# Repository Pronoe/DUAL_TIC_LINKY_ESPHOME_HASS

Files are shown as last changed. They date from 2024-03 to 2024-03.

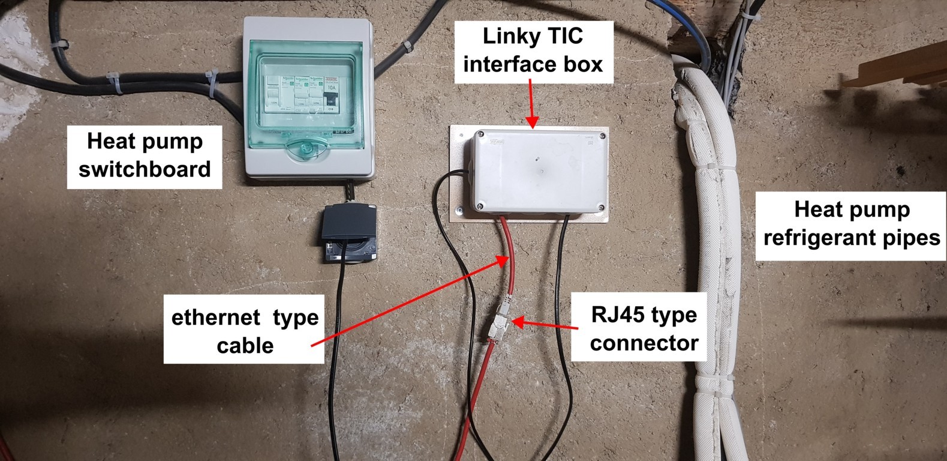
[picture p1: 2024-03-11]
Pictures/installed_linky_box.jpg

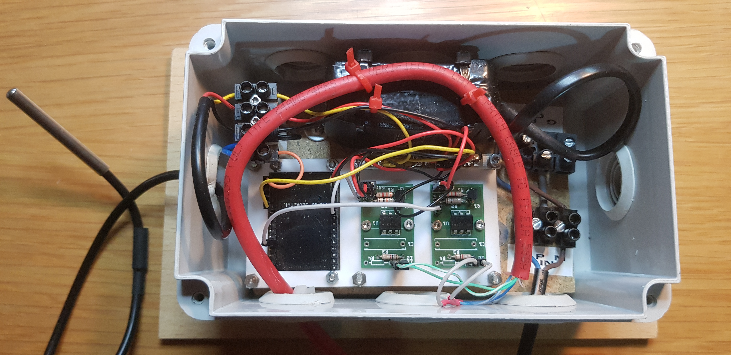
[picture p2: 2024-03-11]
Electronic definition/Pictures/20240217_154911.jpg

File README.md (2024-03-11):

Author: Patrick Souty
  
Dual `Linky` power meter monitoring with `Home Assistant` and `ESP32` for `TIC` data link interface
  
Based on following hardware:
  
- `ESP32` `DOIT-DEVT-KIT-V1` including module `ESP-WROOM32`
- `TIC` optocoupler interface boards
- 5.2V power supply
- 2 Power meters
  - French `Linky` type power meter with `TIC` data link (serial date @ 1200 or 9600 b/s over a 50 kHz carrier)

Software: 

- ` ESPHOME ` for the `ESP32` firmware with teleinfo driver
- `Home-assistant` app running on Raspberry PI3, for monitoring and data analysis

## Project description - English version ##

This project is dedicated to the monitoring of 2 distinct `Linky` power meter (French smart power meter) with a single `ESP32` module as the low level interface and `Home Assistant` for data monitoring.

`ESPHOME` is used to generate the ERSP32 firmware with the use of TELEINFO driver for the `TIC` data link interpretation.
It has been preferred to a `TASMOTA` solution because this later cannot be configured to monitor two separate data links.
Two interface boards based on an optocoupler H11AA1 are used for the `TIC` signal demodulation and galvanic isolation.
This interface insures compliance to the Enedis-NOI-CPT_54E specification document.
There exists a lot of similar projects for the use of `TIC` power meter interface for energy monitoring but I have found none with the ability to monitor two power meter with a single `ESP32` module.

The overall electronic is housed inside a plastic box placed in the boiler room.
It is connected to the two power meters outside the house, through two twisted pairs from an Ethernet cable.
The `ESP32` communicates over Wi-Fi with `Home Assistant` running on a RPI 3B.

## Description du projet -  version Française  ##

Ce projet est destiné au suivi en temps réel des consommations électriques grâce à l'exploitation des liaisons de données `TIC` des compteurs `Linky`. Il utilise un module `ESP32` unique pour la dé-commutation des trames `TIC` des 2 compteurs `Linky` qui équipent ma maison.
Le 1er compteur est dédié presque uniquement à la pompe à chaleur qui chauffe la maison et le 2ème couvre tous les autres usages.
Cela a permis de conserver des contrats de 9 kVA et surtout une installation en monophasé.

`ESPHOME` a été utilisé pour le firmware de l'ERSP32 en le compilant avec le driver TELEINFO  pour la dé-commutation de la liaison `TIC`.
J'ai testé également la solution `TASMOTA` qui était légèrement plus simple à mettre en oeuvre mais je ne l'ai pas retenu car elle ne permet malheureusement pas de gérer simultanément 2 liaisons `TIC`.
Deux cartes d'interface basées sur un optocoupler H11AA1 sont utilisées pour la démodulation du signal `TIC` et pour l'isolation galvanique.
Ces cartes sont nécessaires pour assurer la conformité au document de spécification Enedis-NOI-CPT_54E et pour assurer l'interface avec l'ERC32.
Il existe de nombreux projets similaires destinés à s'interfacer avec les compteurs `Linky` mais je n'en ai trouvé aucun permettant de se connecteur à 2 compteurs simultanément avec un seul module `ESP32`, d'où ce projet spécifique.

L'ensemble de l'électronique est logée dans un boîtier de raccordement électrique et installée dans le local chaufferie.
Elle est connectée aux 2 compteurs à l'extérieur de la maison grâce à un câble Ethernet de 10 m dont 2 des 4 paires torsadées sont utilisées.
Le module `ESP32` communique en Wi-Fi avec `Home Assistant` qui tourne sur un RPI 3B.

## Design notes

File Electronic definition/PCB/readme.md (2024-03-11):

PCB was designed with Fritzing software and manufactured by Aisler Gmbh

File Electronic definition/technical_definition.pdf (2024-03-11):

# LINKY Power Meter interface with ESP32, Zigbee and Home Assistant

## OVERALL ARCHITECTURE

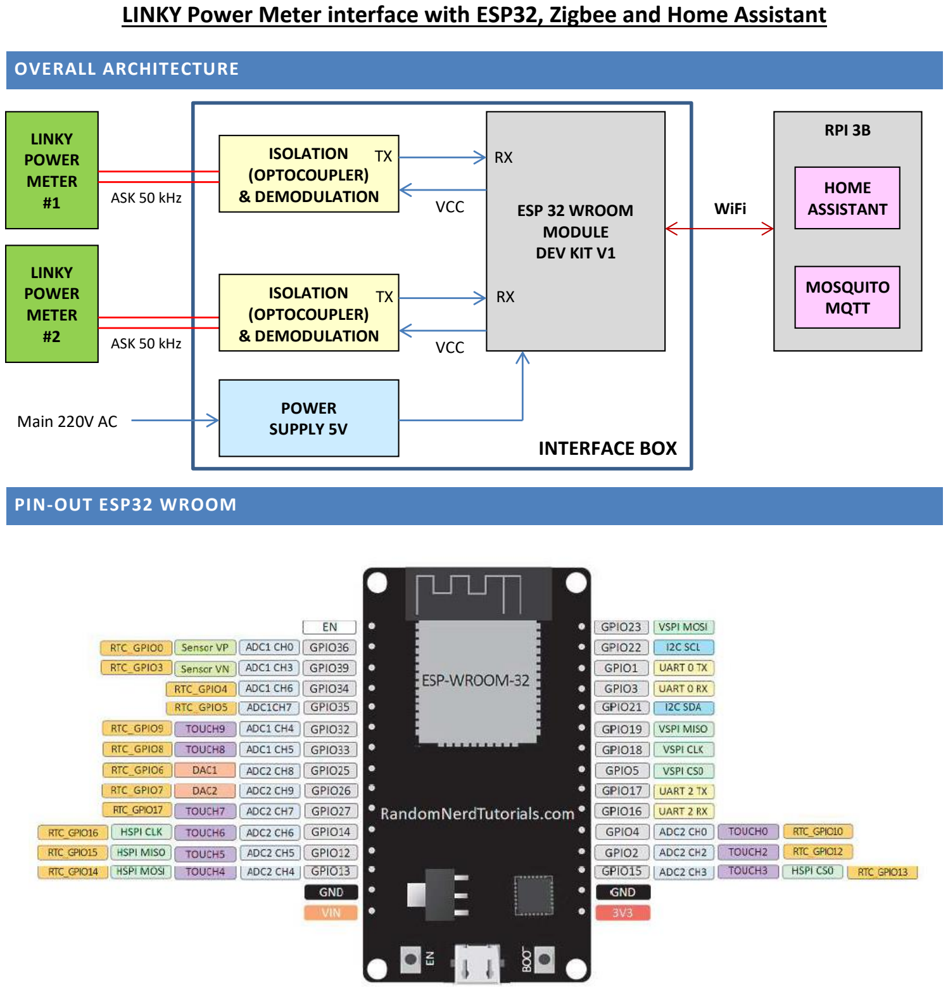
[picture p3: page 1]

## PIN-OUT ESP32 WROOM

## INTERFACE BOX

### LINKY POWER METER

#1

### LINKY POWER METER

#2

### ISOLATION (OPTOCOUPLER)

ASK 50 kHz | & DEMODULATION

ASK 50 kHz

### ISOLATION (OPTOCOUPLER) & DEMODULATION

### ESP 32 WROOM MODULE DEV KIT V1

TX

TX

### VCC

### VCC

RX

RX

### POWER SUPPLY 5V Main 220V AC

### RPI 3B

### HOME ASSISTANT

### MOSQUITO MQTT

### WiFi

## PINOUT OF ERC32 (NOT THE MODULE PINOUT)

Name | No. | Type | Function
GND | 1 | P | Ground
3V3 | 2 | P | Power supply
EN | 3 | I | Module-enable signal. Active high.
SENSOR_VP | 4 | I | GPIO36, ADC1_CH0, RTC_GPIO0
SENSOR_VN | 5 | I | GPIO39, ADC1_CH3, RTC_GPIO3
IO34 | 6 | I | GPIO34, ADC1_CH6, RTC_GPIO4
IO35 | 7 | I | GPIO35, ADC1_CH7, RTC_GPIO5
IO32 | 8 | I/O | GPIO32, XTAL_32K_P (32.768 kHz crystal oscillator input), ADC1_CH4, TOUCH9, RTC_GPIO9
IO33 | 9 | I/O | GPIO33, XTAL_32K_N (32.768 kHz crystal oscillator output), ADC1_CH5, TOUCH8, RTC_GPIO8
IO25 | 10 | I/O | GPIO25, DAC_1, ADC2_CH8, RTC_GPIO6, EMAC_RXD0
IO26 | 11 | I/O | GPIO26, DAC_2, ADC2_CH9, RTC_GPIO7, EMAC_RXD1
IO27 | 12 | I/O | GPIO27, ADC2_CH7, TOUCH7, RTC_GPIO17, EMAC_RX_DV
IO14 | 13 | I/O | GPIO14, ADC2_CH6, TOUCH6, RTC_GPIO16, MTMS, HSPICLK, HS2_CLK, SD_CLK, EMAC_TXD2
IO12 | 14 | I/O | GPIO12, ADC2_CH5, TOUCH5, RTC_GPIO15, MTDI, HSPIQ, HS2_DATA2, SD_DATA2, EMAC_TXD3
GND | 15 | P | Ground
IO13 | 16 | I/O | GPIO13, ADC2_CH4, TOUCH4, RTC_GPIO14, MTCK, HSPID, HS2_DATA3, SD_DATA3, EMAC_RX_ER
SHD/SD2* | 17 | I/O | GPIO9, SD_DATA2, SPIHD, HS1_DATA2, U1RXD
SWP/SD3* | 18 | I/O | GPIO10, SD_DATA3, SPIWP, HS1_DATA3, U1TXD
SCS/CMD* | 19 | I/O | GPIO11, SD_CMD, SPICS0, HS1_CMD, U1RTS
SCK/CLK* | 20 | I/O | GPIO6, SD_CLK, SPICLK, HS1_CLK, U1CTS
SDO/SD0* | 21 | I/O | GPIO7, SD_DATA0, SPIQ, HS1_DATA0, U2RTS
SDI/SD1* | 22 | I/O | GPIO8, SD_DATA1, SPID, HS1_DATA1, U2CTS
IO15 | 23 | I/O | GPIO15, ADC2_CH3, TOUCH3, MTDO, HSPICS0, RTC_GPIO13, HS2_CMD, SD_CMD, EMAC_RXD3
IO2 | 24 | I/O | GPIO2, ADC2_CH2, TOUCH2, RTC_GPIO12, HSPIWP, HS2_DATA0, SD_DATA0
IO0 | 25 | I/O | GPIO0, ADC2_CH1, TOUCH1, RTC_GPIO11, CLK_OUT1, EMAC_TX_CLK
IO4 | 26 | I/O | GPIO4, ADC2_CH0, TOUCH0, RTC_GPIO10, HSPIHD, HS2_DATA1, SD_DATA1, EMAC_TX_ER
IO16 | 27 | I/O | GPIO16, HS1_DATA4, U2RXD, EMAC_CLK_OUT
IO17 | 28 | I/O | GPIO17, HS1_DATA5, U2TXD, EMAC_CLK_OUT_180
IO5 | 29 | I/O | GPIO5, VSPICS0, HS1_DATA6, EMAC_RX_CLK
IO18 | 30 | I/O | GPIO18, VSPICLK, HS1_DATA7
IO19 | 31 | I/O | GPIO19, VSPIQ, U0CTS, EMAC_TXD0
NC | 32 | - | -
IO21 | 33 | I/O | GPIO21, VSPIHD, EMAC_TX_EN
RXD0 | 34 | I/O | GPIO3, U0RXD, CLK_OUT2
TXD0 | 35 | I/O | GPIO1, U0TXD, CLK_OUT3, EMAC_RXD2
IO22 | 36 | I/O | GPIO22, VSPIWP, U0RTS, EMAC_TXD1
IO23 | 37 | I/O | GPIO23, VSPID, HS1_STROBE
GND | 38 | P | Ground

## I/O PINS SELECTION

HW function | PIN | Rational
Power Meter #1 data | GPIO35 (RX0) | Fully available – input only
Power Meter #2 data | GPIO16 (RX2) | Fully available
Temp sensor DS18B20 communication | GPIO14 | Fully available

Note: pullup resistor 4,7 kohm required on temp. sensor data line.

## SCHEMATIC

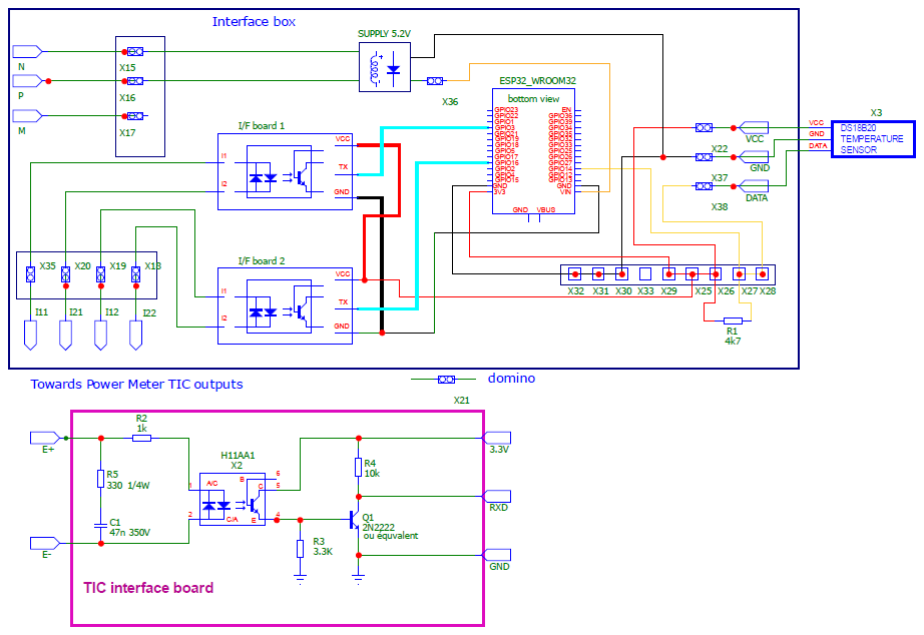
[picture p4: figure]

## PCB ATTACHMENT

### - PCB bracket FDM printing in PLA, with elevation feet - ESP board attached beneath the bracket with electronic parts on the bottom - Interface boards attached over the bracket with electronic parts on the top

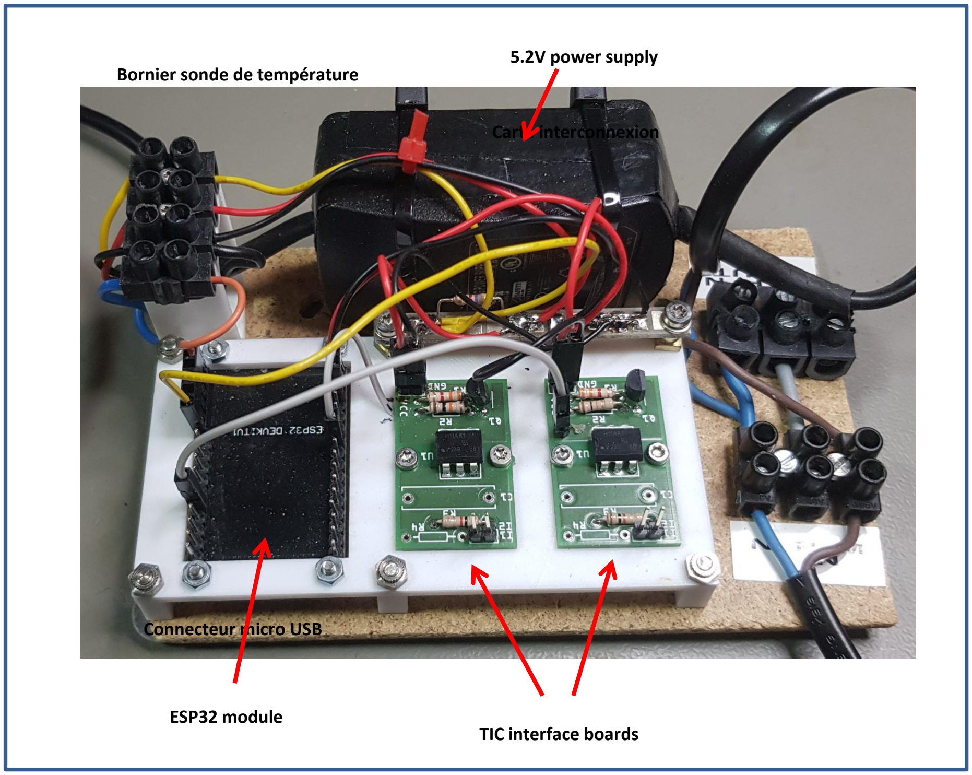
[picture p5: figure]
Connecteur micro USB; 5.2V power supply; Carte interconnexion; Bornier sonde de température; TIC interface boards; ESP32 module

## FINAL HARDWARE IMPLEMENTATION

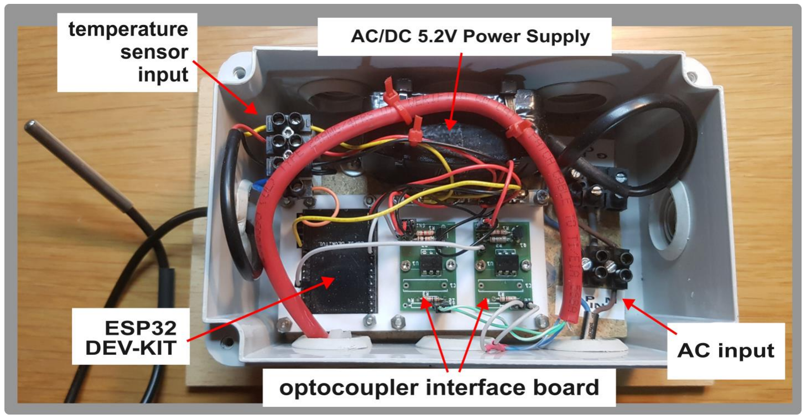
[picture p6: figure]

## POWER CONSUMPTION

### Measurement with a power meter → below 1W

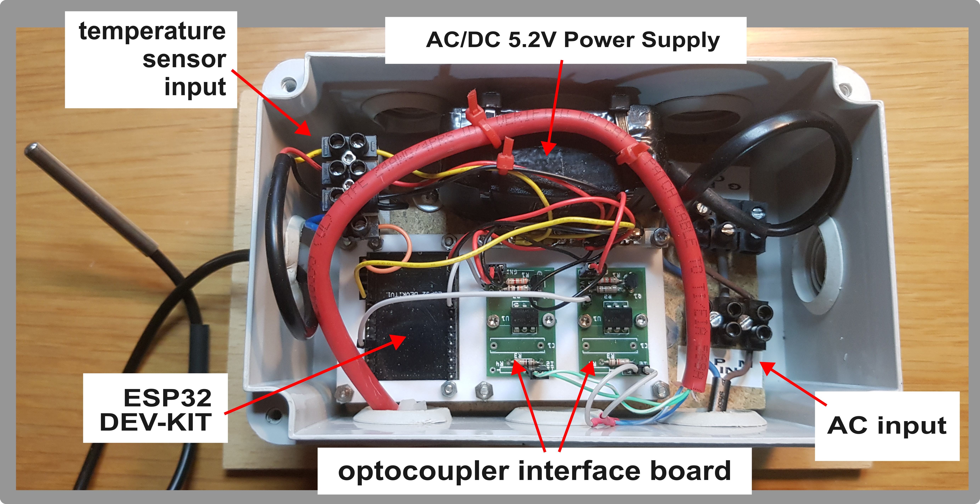
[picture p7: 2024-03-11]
Electronic definition/Pictures/20240217_154911_label.jpg

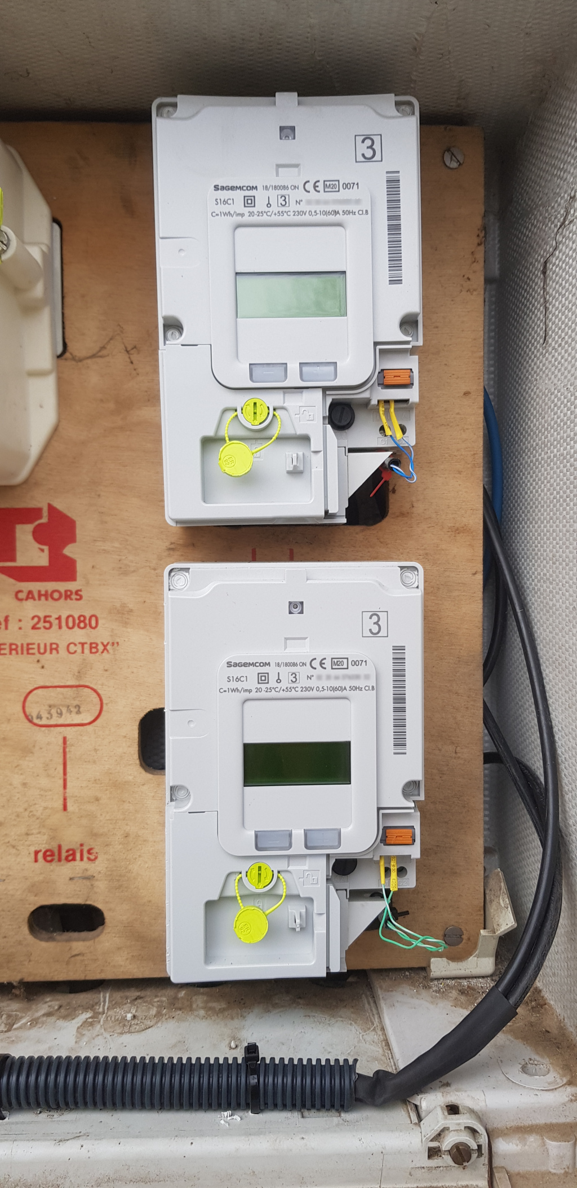
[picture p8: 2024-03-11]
Pictures/meter_cables .jpg

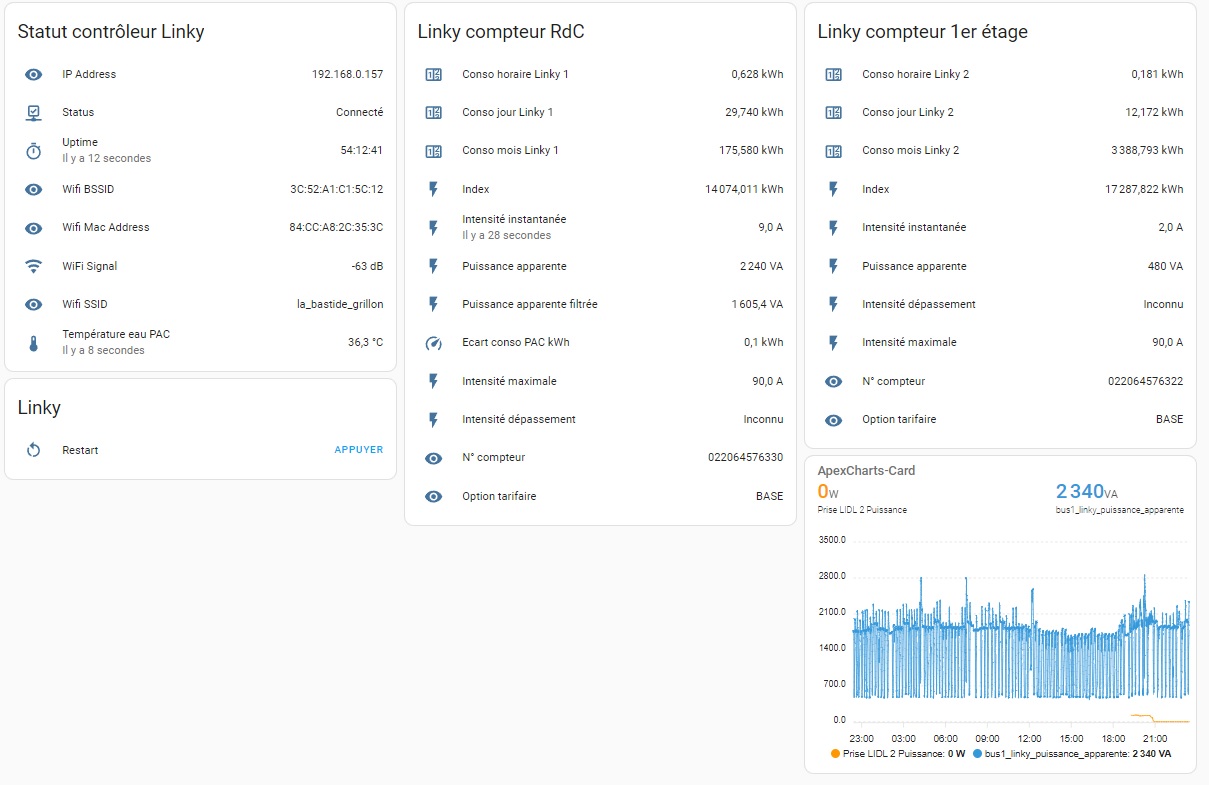
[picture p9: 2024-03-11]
Pictures/home_assistant_dashboard_.jpg

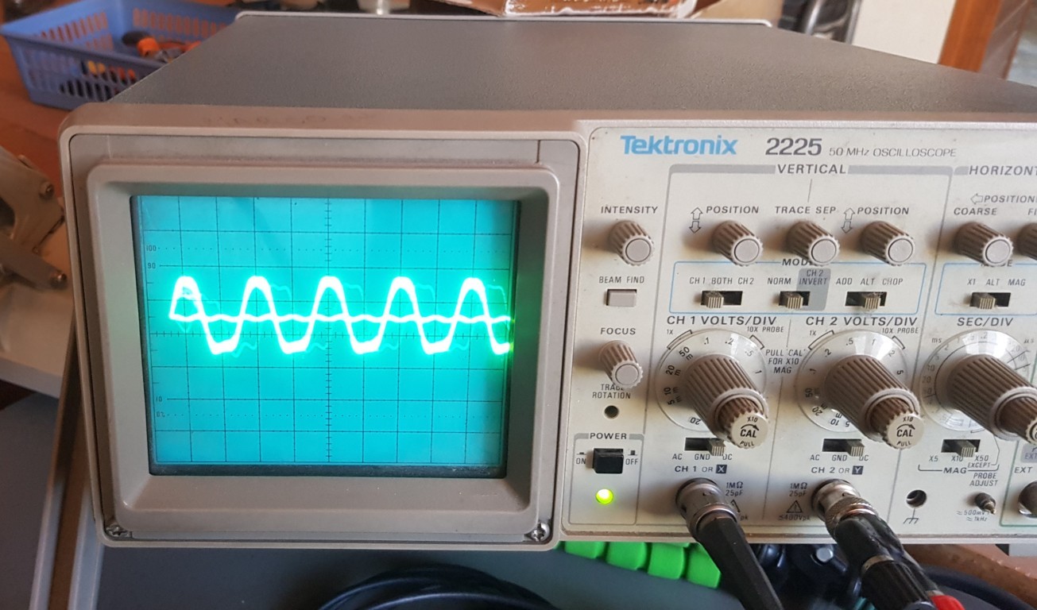
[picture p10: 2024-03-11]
Pictures/TIC_signal.jpg

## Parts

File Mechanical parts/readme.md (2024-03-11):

Mechanical parts (PCB stand and washers) designed with FreeCAD software and 3D printed.

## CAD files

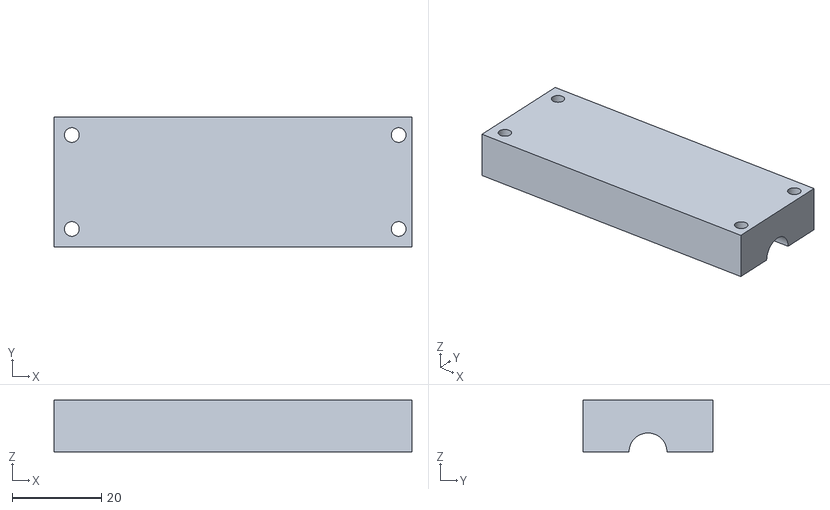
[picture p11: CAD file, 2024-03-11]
Mechanical parts/boitier_RJ45-Demi_boite2.stl
80.4 x 29.1 x 11.6

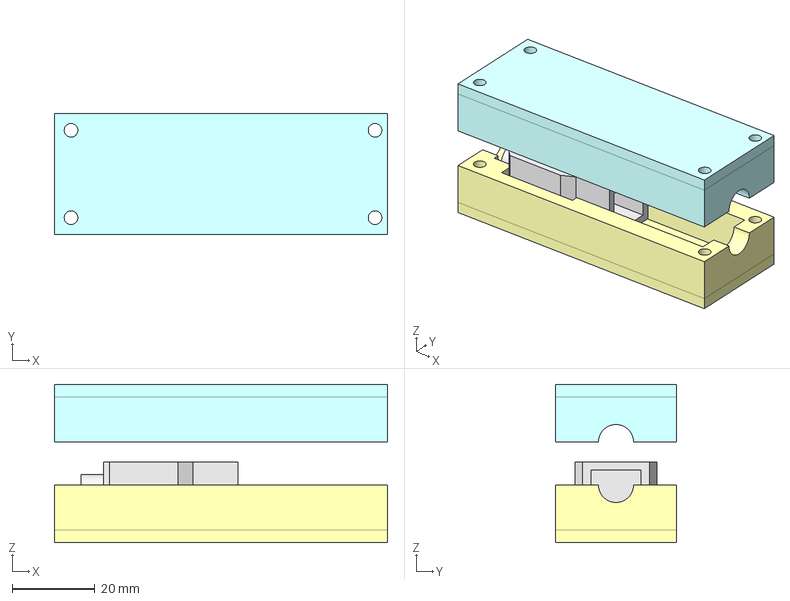
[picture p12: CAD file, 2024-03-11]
Mechanical parts/boitier_RJ45.FCStd
80.4 x 29.1 x 38.2 mm
Modèle connecteur femelle
Demi_boite1
Demi_boite1 (Mirror #1)

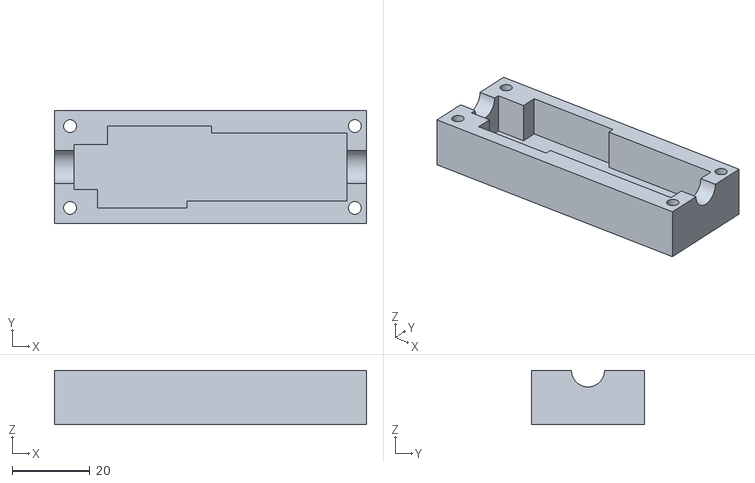
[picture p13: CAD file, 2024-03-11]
Mechanical parts/boitier_RJ45_large.stl
80.4 x 29.1 x 13.9

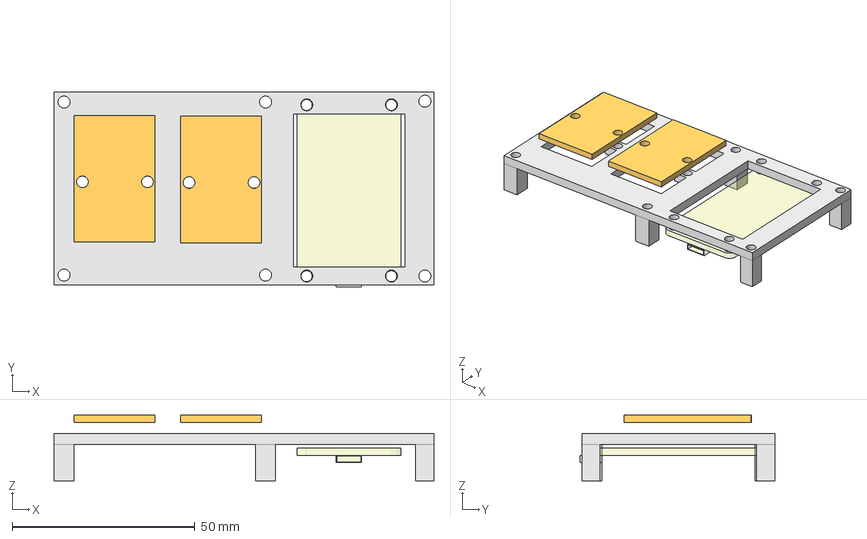
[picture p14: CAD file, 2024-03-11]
Mechanical parts/stand.FCStd
104.1 x 53.4 x 18.0 mm
stand
PCB_KIT_WROOM32
PCB opto
PCB opto001

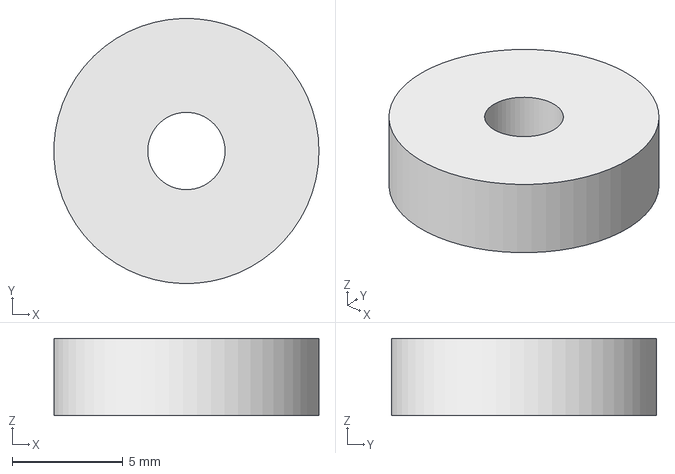
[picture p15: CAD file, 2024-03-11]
Mechanical parts/washer_12x3.5x3.5.FCStd
12.0 x 12.0 x 3.50 mm

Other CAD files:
Mechanical parts/boitier_RJ45.stl
Mechanical parts/stand.stl
Mechanical parts/washer_12x3.5x3.5.stl

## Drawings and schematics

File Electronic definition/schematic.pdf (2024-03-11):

## SUPPLY 5.2V

I/F board 1 | DS18B20

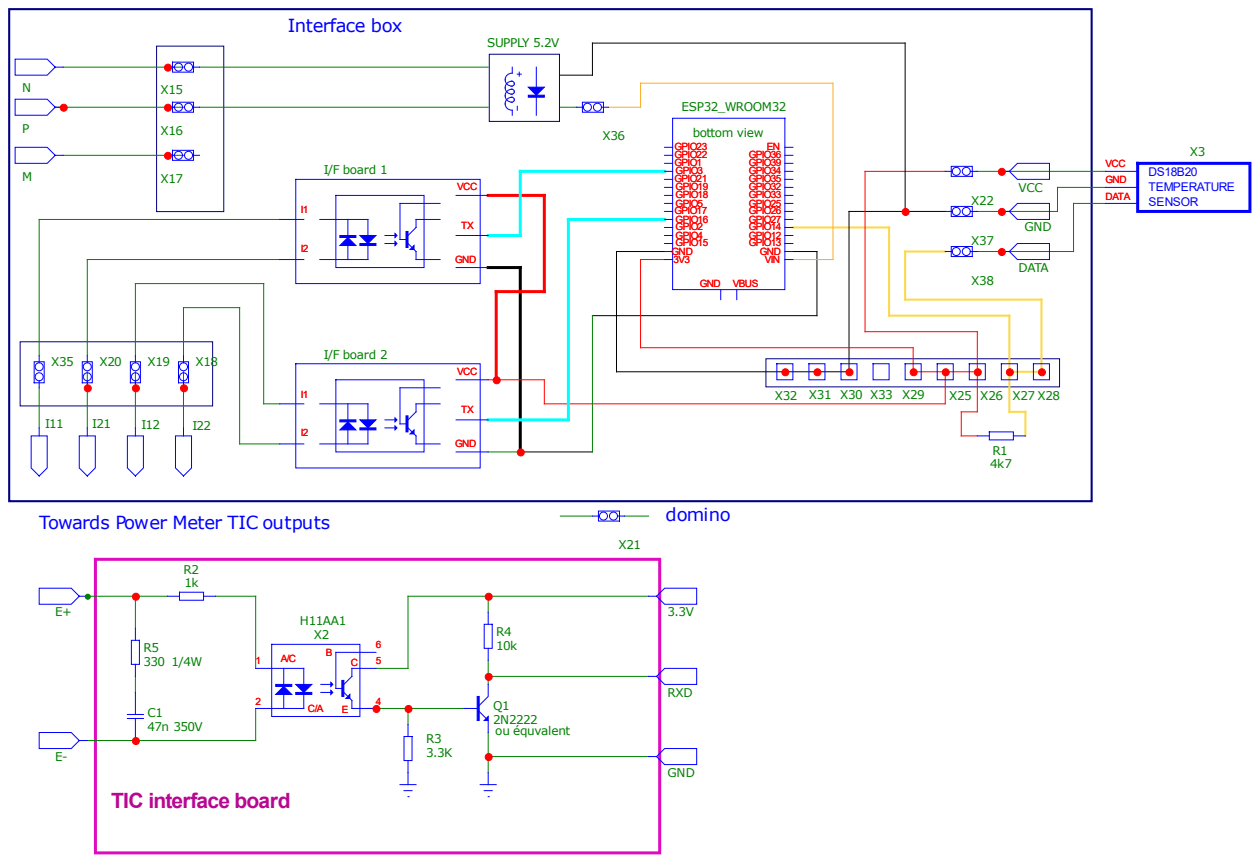
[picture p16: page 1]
GND; VCC; VCC GND DATA; GPIO23 GPIO22 GPIO1 GPIO3 GPIO21 GPIO19 GPIO18 GPIO5 GPIO17 GPIO16 GPIO4; GPIO2 GPIO15 GND 3V3; EN GPIO36 GPIO39 GPIO34 GPIO35 GPIO32 GPIO33 GPIO25 GPIO26 GPIO27 GPIO14 GPIO12 GPIO13 GND VIN; GND VBUS; TEMPERATURE SENSOR; DATA; Q1 2N2222 ou équvalent; RXD; I/F board 2; ESP32_WROOM32; bottom view; Interface box; domino

Towards Power Meter TIC outputs

TIC interface board

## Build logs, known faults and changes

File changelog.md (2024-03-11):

Author : Patrick Souty

-----------------------------------------------------------------------------------------------------------------------
    18/02/2024 : version 1.0 - initial and operational version

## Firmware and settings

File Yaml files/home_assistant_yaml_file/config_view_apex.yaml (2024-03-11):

views:
  - title: Home
    type: custom:layout-card
    layout_type: custom:grid-layout
    layout:
      grid-template-columns: 20% 1fr
      grid-template-areas: |
        "left right"
    cards:
      - type: entities
        entities:
          - entity: sensor.target_pac_water_temp
            name: Température cible eau PAC
          - entity: sensor.filtered_temp_ext
            name: Température extérieure filtrée
            icon: mdi:thermometer
          - entity: sensor.filtered_linky_rdc_va
            name: Puissance apparente moyenne
          - entity: sensor.temperature_dallas_1
            name: Température départ eau PAC
      - type: custom:apexcharts-card
        apex_config:
          chart:
            height: 500px
            width: 100%
          grid:
            show: true
            borderColor: '#90A4AE'
            strokeDashArray: 0
            position: back
            xaxis:
              lines:
                show: true
            yaxis:
              lines:
                show: true
            row:
              colors: undefined
              opacity: 0
            column:
              colors: undefined
              opacity: 0
            padding:
              top: 0
              right: 0
              bottom: 0
              left: 0
        graph_span: 1d
        yaxis:
          - id: temp
            decimals: 0
            min: 0
            max: ~50
            apex_config:
              tickAmount: 5
          - id: VA
            opposite: true
            decimals: 0
            min: 0
            max: ~3000
            apex_config:
              tickAmount: 6
          - id: temp_ext
            opposite: false
            decimals: 0
            min: ~0
            max: ~30
            apex_config:
              tickAmount: 6
              labels:
                style:
                  colors: blue
                  fontSize: 12px
              title:
                text: 19 - temp. ext.°C
                rotate: -90
                offsetX: 0
                offsetY: 0
                style:
                  color: blue
                  fontSize: 12px
                  fontFamily: Helvetica, Arial, sans-serif
                  fontWeight: 600
                  cssClass: apexcharts-yaxis-title
          - id: kWh
            opposite: true
            decimals: 1
            min: ~-1.5
            max: ~1.5
            apex_config:
              tickAmount: 6
        all_series_config:
          stroke_width: 2
          curve: straight
        header:
          show: true
          title: Surveillance PAC
          show_states: true
          colorize_states: true
        series:
          - entity: sensor.netatmo_unite_exterieure_temperature
            transform: return 19-x;
            yaxis_id: temp_ext
            type: line
            color: blue
            name: Ecart temp. extérieure
          - entity: sensor.temperature_dallas_1
            yaxis_id: temp
            type: line
            stroke_width: 1
            color: red
            name: Température eau départ PAC - mesure
            group_by:
              func: avg
              duration: 1min
          - entity: sensor.target_pac_water_temp
            yaxis_id: temp
            type: line
            curve: stepline
            color: orange
            name: Température eau départ PAC - théorique
          - entity: sensor.bus1_linky_puissance_apparente
            yaxis_id: VA
            type: line
            color: green
            name: Puissance PAC (VA)
            group_by:
              func: avg
              duration: 60min
          - entity: sensor.ecart_conso_pac
            yaxis_id: kWh
            type: line
            color: cyan
            name: Ecart conso PAC (kWh)
            group_by:
              func: avg
              duration: 1min
      - type: entities
        entities:
          - entity: sensor.target_pac_water_temp
            name: Température cible eau PAC
          - entity: sensor.filtered_temp_ext
            name: Température extérieure filtrée
            icon: mdi:thermometer
          - entity: sensor.filtered_linky_rdc_va
            name: Puissance apparente moyenne
          - entity: sensor.temperature_dallas_1
            name: Température départ eau PAC
      - apex_config:
          chart:
            height: 500px
          grid:
            show: true
            borderColor: '#90A4AE'
            strokeDashArray: 0
            position: back
            xaxis:
              lines:
                show: true
            yaxis:
              lines:
                show: true
            row:
              colors: undefined
              opacity: 0
            column:
              colors: undefined
              opacity: 0
            padding:
              top: 0
              right: 0
              bottom: 0
              left: 0
        type: custom:apexcharts-card
        graph_span: 3h
        yaxis:
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

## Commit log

2024-03-11 Delete Electronic definition/PCB/TIC_IF_V2.lnk
    Remove useless file
2024-03-11 Create readme.md
    Add information on PCB design tool and manufacturing
